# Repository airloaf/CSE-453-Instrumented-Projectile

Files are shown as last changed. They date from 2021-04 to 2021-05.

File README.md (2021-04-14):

# CSE-453-Instrumented-Projectile

## Introduction

This project is for our Senior design course CSE 453, Hardware Software Integration. Our team was tasked with creating an instrumented projectile capable of taking and storing measurements of its trajectory during launch from an air cannon. The projectile must be capable of withstanding multiple launches. The cannon and subsequently the projectile is made to be used as a demonstration of projectile motion in a school setting.

The Instrumented projectile will house a microcontroller circuit that is outfitted with the necessary sensors to take various measurements, and will be powered by a small rechargeable lithium ion polymer battery. Once the projectile is activated and launched, it will store its real time measurements to the on-board SD card. The user will then be able to review the trajectory measurements after retrieving the projectile.

## Parts List

### Core Parts

-[Arduino Trinket M0](https://www.adafruit.com/product/3500)

-[Adafruit MPU-6050 6-DoF Accel and Gyro Sensor](https://www.adafruit.com/product/3886)

-[Adafruit LiIon/LiPoly Backpack Add-On for Pro Trinket/ItsyBitsy](https://www.adafruit.com/product/2124)

-[Micro SD Card Writer](https://www.adafruit.com/product/254)

### Batteries

-[Lithium Ion Polymer Battery - 3.7v 1200mAh](https://www.adafruit.com/product/258)

-[Lithium Ion Polymer Battery - 3.7v 500mAh](https://www.adafruit.com/product/1578)

-[Lithium Ion Polymer Battery - 3.7v 150mAh](https://www.adafruit.com/product/1317)

### Other Parts

-[Arduino Stackable Header - 6 Pin](https://www.sparkfun.com/products/9280)

-[Foam Balls](https://www.amazon.com/Tourna-Tennis-Practice-Youth-Training/dp/B0076ZITY6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)

-[Piezo Buzzer](https://www.adafruit.com/product/160)

-[Tennis Balls](https://www.amazon.com/Wilson-Sporting-Goods-Prime-Tennis/dp/B07CFH181X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)

-[USB SD Card Reader](https://www.amazon.com/Adapter-Standard-Connector-Smartphones-Function/dp/B01BXSKPES)

## Installing Source Code to Trinket M0

1. Install Circuit Python: ([Trinket M0 Circuit Python Installation](https://learn.adafruit.com/adafruit-trinket-m0-circuitpython-arduino/circuitpython))

2. Copy the contents of ```src/``` into the root directory of the Trinket M0

3. Copy ```libs/Circuit Python``` into the lib folder of the Trinket M0

## Directory Structure

```
docs/               Documentation for assembling the projectile
HardwareTests/      Tests for hardware components in isolation
libs/               Libraries either for the microcontroller code or for fritzing circuits
models/             3D models for the projectile
src/                Circuit Python Source Code
```

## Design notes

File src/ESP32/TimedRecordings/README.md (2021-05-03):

This code will record accelerometer and gyroscopic data for 5 seconds, then it will output the data over bluetooth.

## Format

There will be x lines sent over bluetooth and serial, where x is the total number of readings taken during the 5 second period.
Each line will have the following format

```
Timestamp,Acceleration_x,Acceleration_y,Acceleration_z,Gyro_x,Gyro_y,Gyro_z
```

Note: each value is separated by a comma. After gyro.z, a new line character is printed.

If the accelerometer was read from 1000 times, ther should be 1000 lines of data with 7000 values total (7 per line)

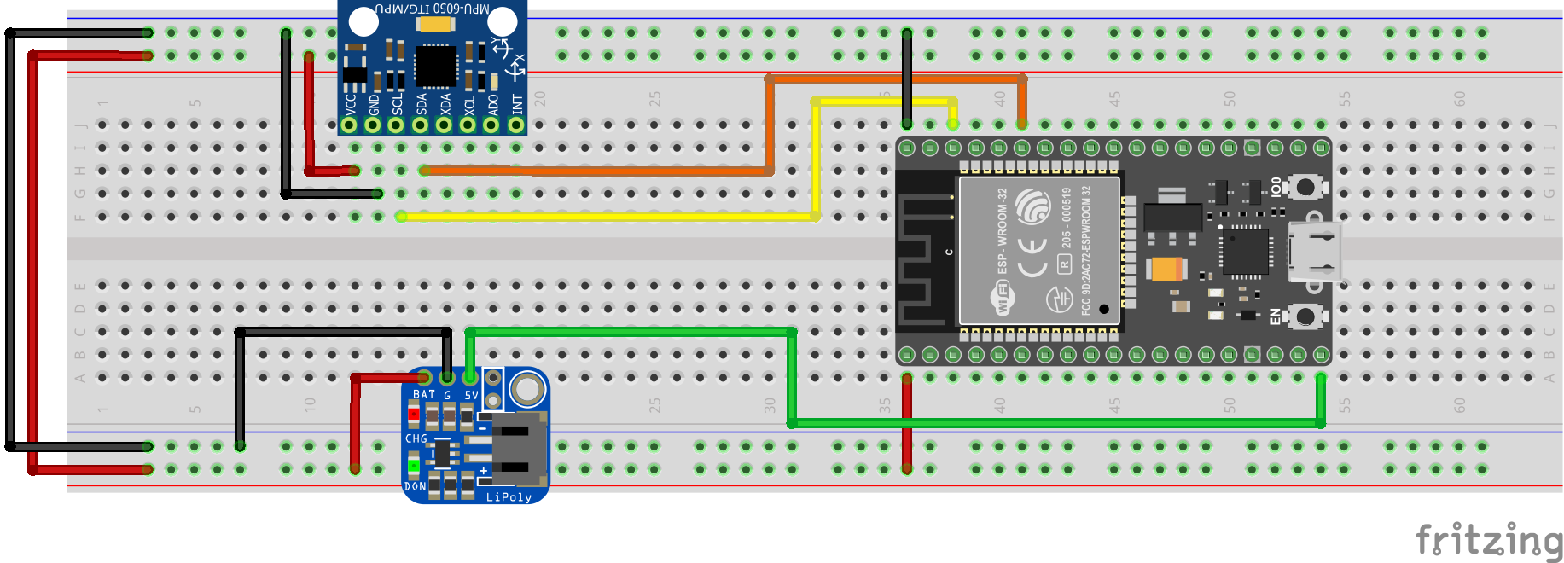
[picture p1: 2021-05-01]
docs/Circuit.png

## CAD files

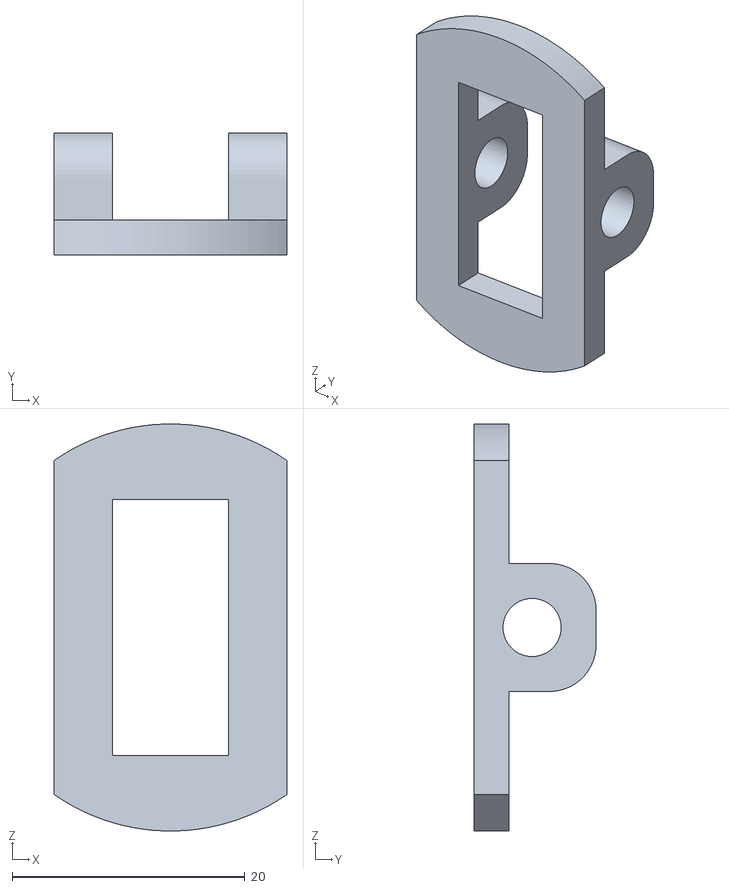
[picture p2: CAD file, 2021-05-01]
models/Fusion 360/PCBCap.stl
20.0 x 10.5 x 35.0

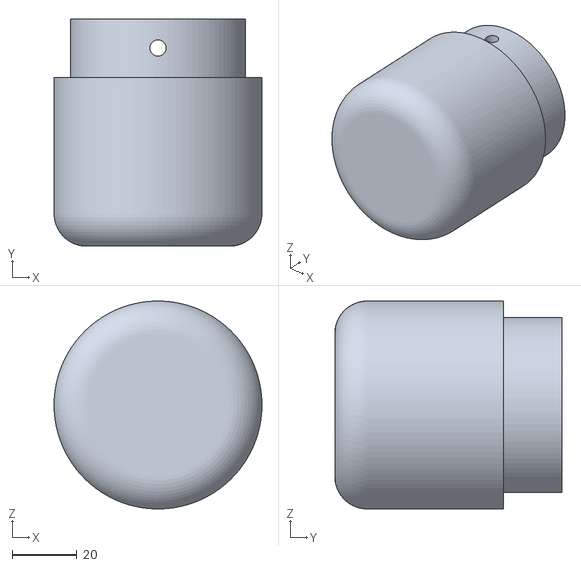
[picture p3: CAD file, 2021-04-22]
models/Fusion 360/Top Projectile.stl
64.0 x 70.0 x 64.0

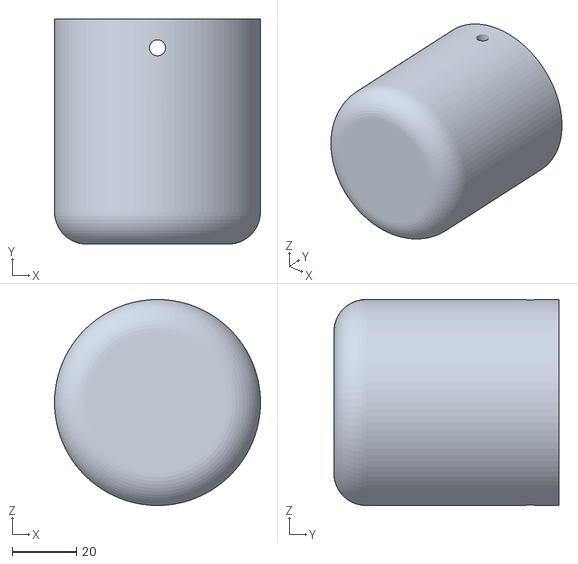
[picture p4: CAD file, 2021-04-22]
models/Fusion 360/Bottom Projectile.stl
64.0 x 70.0 x 64.0

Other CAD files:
models/Fusion 360/PCB Caps.f3d
models/Fusion 360/Projectile Housing.f3d

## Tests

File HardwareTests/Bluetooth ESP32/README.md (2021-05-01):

# Bluetooth on ESP32 development board Test

This test is designed to test the functionality of bluetooth on an ESP 32 development board. You should have some sort of bluetooth monitor capable of outputting the raw character stream into a terminal/textfile/whatever.

## Usage

Upload the Arduino Code to the ESP 32. When the ESP 32 is running, add a bluetooth device to your computer called "ESP32test". In your bluetooth serial monitor, connect to the ESP32test device. Open up the serial monitor from the Arduino IDE and enter anything into the serial input. You should see it output to the bluetooth serial monitor.

## References

[Bluetooth Guide](https://randomnerdtutorials.com/esp32-bluetooth-classic-arduino-ide/#:~:text=The%20ESP32%20comes%20with%20Wi,Low%20Energy%20and%20Bluetooth%20Classic.&text=We'll%20control%20an%20ESP32,only%20compatible%20with%20Android%20smartphones.)

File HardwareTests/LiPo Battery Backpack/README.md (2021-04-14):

# LiPoly Backpack

This test is designed to test the usage of a Lithium Polymer battery on the Trinket M0.

Note: Pay close attention to the pinout diagram.

## Usage

Assemble the circuit as shown in the WiringDiagram.png. Disconnect the trinket M0 from USB and observe it is still activated.

## WiringDiagram

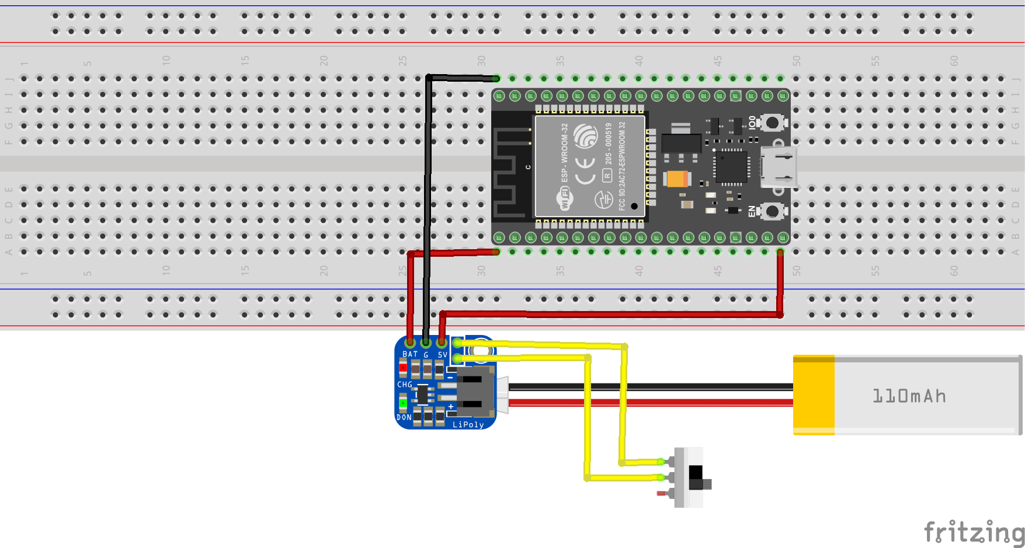
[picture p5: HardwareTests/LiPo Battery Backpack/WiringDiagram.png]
Wiring Diagram


## References

[Pinout Description](https://learn.adafruit.com/adafruit-pro-trinket-lipoly-slash-liion-backpack/pinouts)

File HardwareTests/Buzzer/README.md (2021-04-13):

# Piezo Buzzer Test

This test is designed to test the usage of a Piezo Buzzer on an Arduino Trinket M0. The code will be using Circuit Python.

## Usage

Assemble the circuit as shown in WiringDiagram.png. Install Circuit Python on the Trinket M0, if it is not currently installed. Then copy src/main.py into the Trinket M0 root directory. If you want to turn on and off the buzzer, simply set the buzzer.duty_cycle to ON or OFF respectively.

## Wiring Diagram

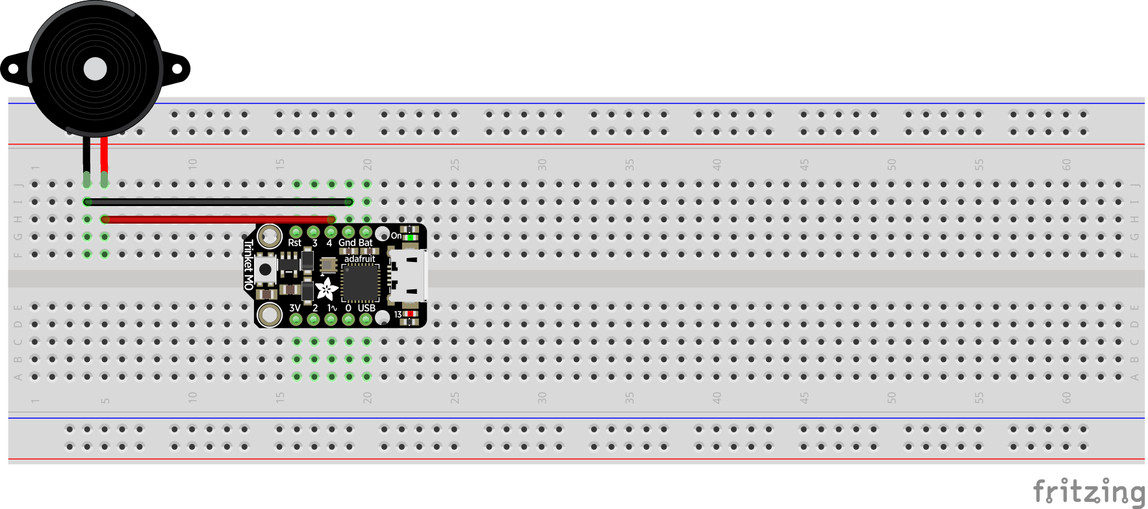
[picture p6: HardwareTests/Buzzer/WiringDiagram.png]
Wiring Diagram


## References

[Adafruit Guide](https://learn.adafruit.com/using-piezo-buzzers-with-circuitpython-arduino)

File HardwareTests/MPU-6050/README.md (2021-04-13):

# MPU-6050 Accelerometer + Gyroscope

This test is designed to test the usage of the MPU 6050 with an Arduino Uno. Even though the trinket m0 is the main microprocessor we target, we will be using the Uno for this test.

## Usage

Assemble the circuit as shown in WiringDiagram.png. If you are using the Arduino ide, you can view the output of the MPU-6050 in the Serial Monitor.

## Wiring Diagram

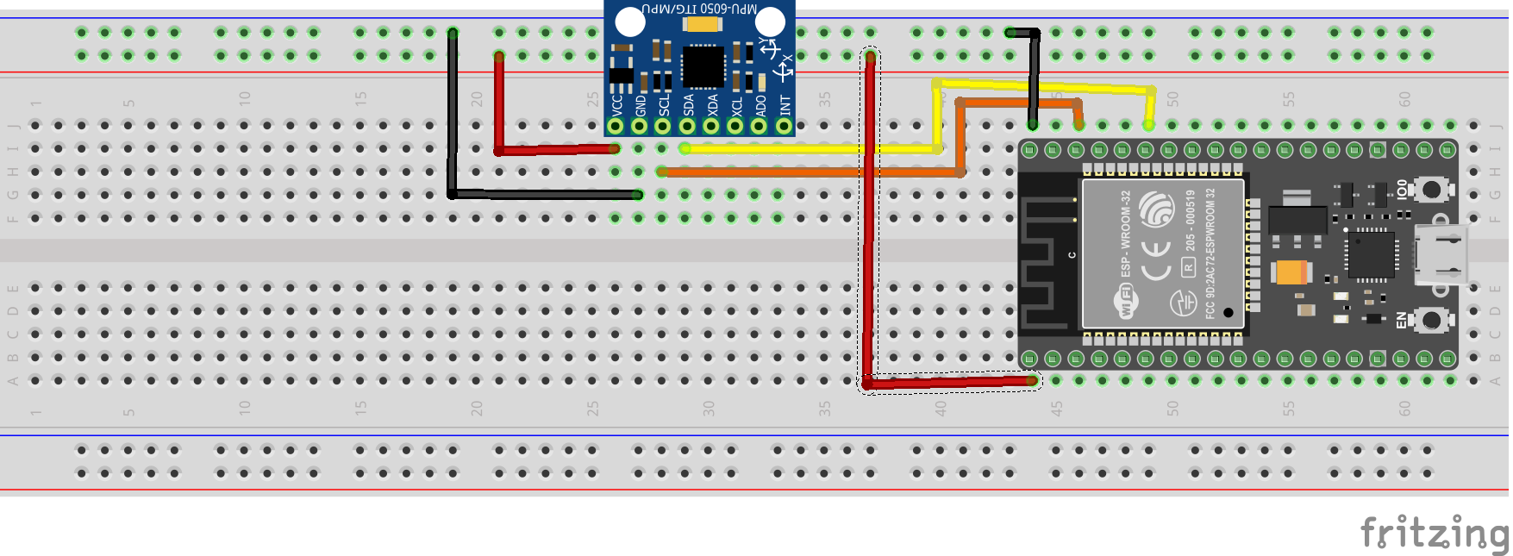
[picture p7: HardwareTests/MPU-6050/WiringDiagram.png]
Wiring Diagram


## References

[Adafruit Guide](https://learn.adafruit.com/mpu6050-6-dof-accelerometer-and-gyro)

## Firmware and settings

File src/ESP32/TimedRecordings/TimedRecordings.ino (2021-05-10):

#include <Adafruit_MPU6050.h>
#include <Adafruit_Sensor.h>
#include <Wire.h>

#include "BluetoothSerial.h"

#if !defined(CONFIG_BT_ENABLED) || !defined(CONFIG_BLUEDROID_ENABLED)
#error Bluetooth is not enabled! Please run `make menuconfig` to and enable it
#endif

#define RECORDING_LENGTH (5 * 1000)
#define RECORDING_PERIOD 10

#define START_BUFFER_SIZE 21

#define MAG_CHECK_PERIOD 10
#define START_MAGNITUDE_THRESHOLD 30

#define IDLE_STATE 1
#define RECORD_STATE 2
#define OFFLOAD_STATE 3
#define RESET_STATE 4

Adafruit_MPU6050 mpu;
BluetoothSerial SerialBT;

static float dataBuf[10000];

unsigned int count;
unsigned int numDataPoints;

static float startBuf[START_BUFFER_SIZE];
unsigned int startCount;
unsigned int prevStartBufTime;

unsigned int recordingStartTime;
unsigned int currentState;
unsigned int prevMagTime;
bool hasRecorded;
float prevMag;

void idle();
void record();
void recordDataPoint();
void offloadData();
void reset();
void maintainStartBuffer();
bool checkMag();

void setup(void)
{
    Serial.begin(9600);
    SerialBT.begin("Instrumented_Projectile");
    Serial.println("Instrumented Projectile Setup");

    while (!Serial)
        delay(10); // will pause Zero, Leonardo, etc until serial console opens

    // Try to initialize!
    if (!mpu.begin()) {
        Serial.println("Failed to find MPU6050 chip");
        while (1) {
            delay(10);
        }
    }

    mpu.setAccelerometerRange(MPU6050_RANGE_8_G);
    mpu.setGyroRange(MPU6050_RANGE_500_DEG);
    mpu.setFilterBandwidth(MPU6050_BAND_21_HZ);

    count = 0;
    numDataPoints = 0;
    currentState = IDLE_STATE;
    prevMag = 10;
    prevMagTime = millis();
    startCount = 0;
    prevStartBufTime = millis();
    hasRecorded = false;

    Serial.print("Setup complete.\n");
    delay(100);
}

void loop()
{
    switch (currentState) {
    case IDLE_STATE:
        idle();
        break;

    case RECORD_STATE:
        record();
        break;

    case OFFLOAD_STATE:
        offloadData();
        break;

    case RESET_STATE:
        reset();
        break;

    default:
        Serial.print("Error: currentState is invalid.");
        SerialBT.print("Error: currentState is invalid.");
    }
}

void idle()
{
    if (SerialBT.available()) {
        // Newline on other device should be using 'LF' setting for proper parsing with this method.
        String btMessage = SerialBT.readStringUntil('\n');
        Serial.print("Recieved message: '" + btMessage + "'\n");
        if (btMessage == "record") {
            // Does not use startBuffer if using mesage to start.
            Serial.print("Entering RECORD_STATE.\n");
            recordingStartTime = millis();
            currentState = RECORD_STATE;
        } else if (btMessage == "data") {
            currentState = OFFLOAD_STATE;
        } else if (btMessage == "reset") {
            currentState = RESET_STATE;
        } else {
            SerialBT.print("Invalid message: '" + btMessage + "'\n");
            SerialBT.print("String length: " + String(btMessage.length()) + "\n");
            Serial.print("Invalid message: '" + btMessage + "'\n");
            Serial.print("String length: " + String(btMessage.length()) + "\n");
        }
    }

    // Starts recording if the acceleration magnitude is greater than the threshold.
    if (!hasRecorded && millis() - prevMagTime > MAG_CHECK_PERIOD && checkMag()) {
        Serial.print("Exceeded starting magnitude threshhold..\n");
        Serial.print("Entering RECORD_STATE.\n");
        for (int i = 0; i < startCount; i++) {
            dataBuf[count++] = startBuf[i];
        }
        numDataPoints += startCount/7;
        currentState = RECORD_STATE;
    }
    else if (!hasRecorded) {
      maintainStartBuffer();
    }
}


void record()
{
  Serial.println("Entering Recording State");

  recordingStartTime = millis();
  unsigned long int curTime = recordingStartTime;
  unsigned long int maxTime = curTime + RECORDING_LENGTH;
  unsigned long int magCheckTime = curTime + MAG_CHECK_PERIOD;

  while (curTime < maxTime /* TODO: Maybe put MAG check here */)
  {
    // Record a single data point
    recordDataPoint();
    curTime += RECORDING_PERIOD;
    delay(RECORDING_PERIOD);
  }

  Serial.println("Leaving Recording State");
  hasRecorded = true;
  currentState = IDLE_STATE;
}

void recordDataPoint()
{
    /* Get new sensor events with the readings */
    sensors_event_t a, g, temp;
    mpu.getEvent(&a, &g, &temp);

    // Store each reading
    dataBuf[count++] = (float) (millis());
    dataBuf[count++] = a.acceleration.x;
    dataBuf[count++] = a.acceleration.y;
    dataBuf[count++] = a.acceleration.z;
    dataBuf[count++] = g.gyro.x;
    dataBuf[count++] = g.gyro.y;
    dataBuf[count++] = g.gyro.z;

    // increment number of data points
    numDataPoints++;
}

void offloadData()
{
    Serial.println("Entering OFFLOAD_STATE.");
    Serial.print(numDataPoints); Serial.println(" number of data points");
    // Output the data.
    SerialBT.print("Timestamp,Acceleration_x,Acceleration_y,Acceleration_z,Gyro_x,Gyro_y,Gyro_z\n");

    for (int i = 0; i < numDataPoints; i++) {
        for (int j = 0; j < 6; j++) {
            SerialBT.print(dataBuf[(i*7) + j]);
            SerialBT.print(',');
        }
        SerialBT.print(dataBuf[(i*7) + 6]);
        SerialBT.print('\n');
    }

    SerialBT.println("END");
    Serial.println("Leaving OFFLOAD_STATE.");
    currentState = IDLE_STATE;
}

void reset() {
    count = 0;
    numDataPoints = 0;
    currentState = IDLE_STATE;
    prevMag = 10;
    prevMagTime = millis();
    startCount = 0;
    prevStartBufTime = millis();
    hasRecorded = false;
}

void maintainStartBuffer() {
  if (millis() - prevStartBufTime > RECORDING_PERIOD) {
    if (startCount == START_BUFFER_SIZE) {
      for (int i = 7; i < START_BUFFER_SIZE; i++) {
        startBuf[i-7] = startBuf[i];
      }
      startCount -= 7;
    }
    /* Get new sensor events with the readings */
    sensors_event_t a, g, temp;
    mpu.getEvent(&a, &g, &temp);

    // Store each reading
    startBuf[startCount++] = (float) (millis());
    startBuf[startCount++] = a.acceleration.x;
    startBuf[startCount++] = a.acceleration.y;
    startBuf[startCount++] = a.acceleration.z;
    startBuf[startCount++] = g.gyro.x;
    startBuf[startCount++] = g.gyro.y;
    startBuf[startCount++] = g.gyro.z;
  }
}

bool checkMag()
{
    /* Get new sensor events with the readings */
    sensors_event_t a, g, temp;
    mpu.getEvent(&a, &g, &temp);

    float mag = sqrt(sq(a.acceleration.x) + sq(a.acceleration.y) + sq(a.acceleration.z));

    if (abs(mag - prevMag) > START_MAGNITUDE_THRESHOLD) {
        prevMagTime = millis();
        prevMag = 10;
        return true;
    }
    prevMagTime = millis();
    prevMag = mag;
    return false;
}

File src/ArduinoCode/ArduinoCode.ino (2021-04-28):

// Basic demo for accelerometer readings from Adafruit MPU6050

#include <Adafruit_MPU6050.h>
#include <Adafruit_Sensor.h>
#include <Wire.h>
#include <string>  

Adafruit_MPU6050 mpu;
float buf[7000];
int count = 0;
bool dataSent = false;

void setup(void) {

  for (int i = 0; i < 14; i++) {
    buf[count++] = 1.02;
  }
  
  Serial.begin(9600);
  while (!Serial)
    delay(10); // will pause Zero, Leonardo, etc until serial console opens

//  Serial.println("Adafruit MPU6050 test!");

  // Try to initialize!
  if (!mpu.begin()) {
//    Serial.println("Failed to find MPU6050 chip");
    while (1) {
      delay(1);
    }
  }
//  Serial.println("MPU6050 Found!");

  mpu.setAccelerometerRange(MPU6050_RANGE_8_G);
//  Serial.print("Accelerometer range set to: ");
  switch (mpu.getAccelerometerRange()) {
  case MPU6050_RANGE_2_G:
//    Serial.println("+-2G");
    break;
  case MPU6050_RANGE_4_G:
//    Serial.println("+-4G");
    break;
  case MPU6050_RANGE_8_G:
//    Serial.println("+-8G");
    break;
  case MPU6050_RANGE_16_G:
//    Serial.println("+-16G");
    break;
  }
  mpu.setGyroRange(MPU6050_RANGE_500_DEG);
//  Serial.print("Gyro range set to: ");
  switch (mpu.getGyroRange()) {
  case MPU6050_RANGE_250_DEG:
//    Serial.println("+- 250 deg/s");
    break;
  case MPU6050_RANGE_500_DEG:
//    Serial.println("+- 500 deg/s");
    break;
  case MPU6050_RANGE_1000_DEG:
//    Serial.println("+- 1000 deg/s");
    break;
  case MPU6050_RANGE_2000_DEG:
//    Serial.println("+- 2000 deg/s");
    break;
  }

  mpu.setFilterBandwidth(MPU6050_BAND_21_HZ);
//  Serial.print("Filter bandwidth set to: ");
  switch (mpu.getFilterBandwidth()) {
  case MPU6050_BAND_260_HZ:
//    Serial.println("260 Hz");
    break;
  case MPU6050_BAND_184_HZ:
//    Serial.println("184 Hz");
    break;
  case MPU6050_BAND_94_HZ:
//    Serial.println("94 Hz");
    break;
  case MPU6050_BAND_44_HZ:
//    Serial.println("44 Hz");
    break;
  case MPU6050_BAND_21_HZ:
//    Serial.println("21 Hz");
    break;
  case MPU6050_BAND_10_HZ:
//    Serial.println("10 Hz");
    break;
  case MPU6050_BAND_5_HZ:
//    Serial.println("5 Hz");
    break;
  }

//  Serial.println("");
  delay(100);
}

void loop() {

  /* Get new sensor events with the readings */
  sensors_event_t a, g, temp;
  mpu.getEvent(&a, &g, &temp);

//  Serial.println(Serial.available());
  if (Serial.available() > 5 && !dataSent) {
    for (int i = 0; i <= count; i++) {
      byte* data = (byte *) &buf[i];
      Serial.write(data, sizeof(float));
    }
    dataSent = true;
  }
  else {
    buf[count++] = (float) millis();
    buf[count++] = a.acceleration.x;
    buf[count++] = a.acceleration.y;
    buf[count++] = a.acceleration.z;
    buf[count++] = g.gyro.x;
    buf[count++] = g.gyro.y;
    buf[count++] = g.gyro.z;
  }

  delay(10);
}

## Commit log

2021-03-25 Added arduino setup to test the 6-Axis Accelerometer
2021-04-13 Added fritzing diagram to the docs.
    [Circuit.fzz]
2021-04-13 Updated Hardware Tests for the Buzzer and the MPU-6050.
    [BuzzerFritzing.fzz]
2021-04-14 Added 3D models to repo
    [Bottom Component.stl, Projectile Housing.f3d, Top Projectile.stl]
2021-04-14 Added metal insert holes to the model
    [Bottom Component.stl, Projectile Housing.f3d, Top Projectile.stl]
2021-04-14 Added current source code to repo
2021-04-14 Added Circuit python libraries
2021-04-14 Tested battery usage with the Trinket M0.
    [Circuit.fzz]
2021-04-14 AddUpdated outter radius of model to be closer to a tennis ball.
    [Bottom Component.stl, Top Projectile.stl]
2021-04-15 Added updated models
    [Bottom Component.stl, Bottom Projectile.stl, Projectile Housing.f3d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]
2021-04-22 Added PCB Caps. Also added updated Projectile housing CAD.
    [Bottom Projectile.stl, PCB Caps.f3d, PCBCap.stl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]
2021-05-01 Updated wiring to reflect the ESP-32 for the MPU 6050 test.
    [Circuit.fzz]
2021-05-01 Updated circuit diagram for the battery recharger.
    [Circuit.fzz]
2021-05-01 Updated wiring diagrams for overall circuit. Added 3v and ground to the 6050 wiring diagram.
    [Circuit.fzz]
2021-05-01 Updated the PCB caps to remove the weird edges from it.
    [PCB Caps.f3d, PCBCap.stl]
2021-05-03 Added states to code. ESP32 now can recieve and interpret messages. ESP32 now has a magnitude threshold between measurements to determine if recording should start (time and magnitude needs to be twe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
2021-05-09 Created Java GUI to select Bluetooth Devices
2021-05-10 Added some code for connecting to a bluetooth device.
2021-05-10 Added a RESET_STATE that will reset all value and allow for re-recording without shutting down the device.
    [TimedRecordings.ino]
2021-05-12 Updated offloader to have a reset button. Updated REAMDE with dependencies
